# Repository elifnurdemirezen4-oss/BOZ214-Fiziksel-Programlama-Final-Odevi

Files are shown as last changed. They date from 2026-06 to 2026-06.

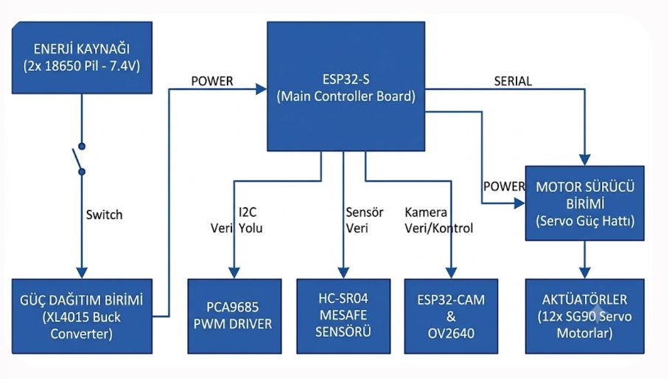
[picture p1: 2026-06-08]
docs/şema.jpeg

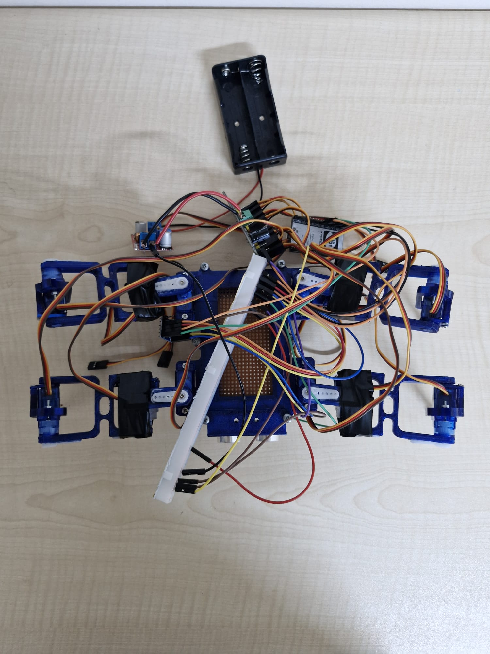
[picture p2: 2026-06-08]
docs/dort_bacak1.jpeg

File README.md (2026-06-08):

dort_bacak2

# SPİDER ASSİST (DÖRT BACAK)

Bu proje, her bacağında iki eklem (Coxa ve Tibia) bulunan, toplam 8 servo motor ile hareket eden dört bacaklı (quadruped) bir robotun donanım ve yazılım altyapısını içermektedir. Sistem, ESP32 mikrodenetleyicisi üzerinden Bluetooth Low Energy (BLE) protokolü ile haberleşmekte ve Python tabanlı bir masaüstü arayüzü ile kontrol edilmektedir.

## 🎯 Proje Amacı 

Bu projenin temel amacı, hareket kısıtlılığı yaşayan bireylerin çevresel bağımsızlıklarını artırmak üzere; Bluetooth Low Energy (BLE) üzerinden uzaktan kontrol edilebilen, otonom engel algılama refleksine sahip, 8 serbestlik dereceli (8-DOF) bir masaüstü mekatronik robot asistan geliştirmektir. Geliştirilen bu sistem, kullanıcı dostu bir arayüz ile mekatronik donanımı entegre ederek, engelli bireylerin asgari fiziksel eforla bulundukları kısıtlı alanlarda güvenli bir şekilde erişim ve kontrol sağlamalarına olanak tanımayı hedeflemektedir.
## 📌 Proje Özellikleri

* **Kablosuz Kontrol:** BLE (Bluetooth Low Energy) teknolojisi kullanılarak düşük gecikmeli, asenkron motor kontrolü.
* **Engelden Kaçma Otonomisi:** HC-SR04 ultrasonik sensörü ile 15 cm altındaki engellerin tespiti. Engel algılandığında motorlar durdurulur ve arayüze anlık uyarı gönderilir.
* **Yumuşak Hareket Algoritması (Smooth Kinematics):** Servo motorların ani akım çekmesini ve mekanik hasar görmesini engellemek amacıyla `yumusakHareket` fonksiyonu ile kademeli açı geçişleri.
* **Güç Tasarrufu:** Robot durur pozisyondayken PWM sinyalleri kesilerek motorlar serbest bırakılır (`motorlariSerbestBirak`), böylece aşırı ısınma ve güç tüketimi önlenir.
* **Kullanıcı Arayüzü (GUI):** Python `Tkinter` ve `Bleak` kütüphaneleri kullanılarak geliştirilmiş, klavye kısayollarını (W, A, S, X) destekleyen asenkron masaüstü kontrol yazılımı.

## 🛠️ Donanım Gereksinimleri

* 1x ESP32 (veya ESP32-S3) Mikrodenetleyici
* 1x PCA9685 16-Kanal PWM Servo Sürücü Modülü (I2C Adresi: 0x40)
* 8x Servo Motor (SG90, MG90S vb.)
* 1x HC-SR04 Ultrasonik Mesafe Sensörü
* 1x XL4015 Voltaj Düşürücü (Buck)
* 1x 3.3V-5V Lojik Dönüştürücü
* 2x 18650 Li-ion Pil (Sistem güç kaynağı)

## 🖨️ 3D Baskı ve Mekanik Tasarım

Robotun fiziksel gövdesini ve eklem parçalarını oluşturmak için gerekli olan tüm `.stl` uzantılı 3D model dosyaları `3d_models/` klasöründe sunulmuştur. Parçaların üretimi için standart PLA malzeme ve optimum dayanıklılık/ağırlık dengesi için %30 doluluk (infill) oranı önerilmektedir.

## 💻 Kullanılan Teknolojiler ve Kütüphaneler

**Gömülü Yazılım (C++ / Arduino IDE):**
* `Wire.h` - I2C iletişimi
* `Adafruit_PWMServoDriver.h` - PCA9685 kontrolü
* `BLEDevice.h`, `BLEServer.h`, `BLEUtils.h`, `BLE2902.h` - Bluetooth BLE protokolü

**Masaüstü Yazılımı (Python):**
* `tkinter` - Grafiksel Kullanıcı Arayüzü (GUI)
* `asyncio` & `threading` - Asenkron BLE haberleşmesi ve arayüz tepkiselliği
* `bleak` - Platform bağımsız BLE istemci bağlantısı

## 🚀 Kurulum ve Çalıştırma

### 1. Mikrodenetleyicinin Programlanması
1. Arduino IDE üzerinde ESP32 kart paketinin yüklü olduğundan emin olun.
2. `Adafruit PWM Servo Driver Library` kütüphanesini kütüphane yöneticisinden kurun.
3. Repoda bulunan `.ino` uzantılı dosyayı ESP32 kartınıza yükleyin. 

### 2. Python Arayüzünün Çalıştırılması
Python ortamınızda gerekli kütüphaneleri kurun:
```bash
pip install bleak asyncio.
```
### 3. `software/python_ble_gui` dizinine gidin ve arayüzü başlatın:
   ```bash
   cd software/python_ble_gui
   python controller.py
   ```
### 4. 
Arayüz açıldığında "Bluetooth ile Robota Bağlan" butonuna tıklayarak eşleşmeyi tamamlayın. Klavye üzerinden (W, A, S) kısayollarını kullanarak veya butonlarla robotu kontrol edebilirsiniz.

## 👥 Proje Yürütücüleri
* Furkan Solmaz
* Elif Nur Demirezen

## 📄 Lisans

Bu proje MIT Lisansı ile lisanslanmıştır. Daha fazla bilgi için `LICENSE` dosyasına göz atabilirsiniz.

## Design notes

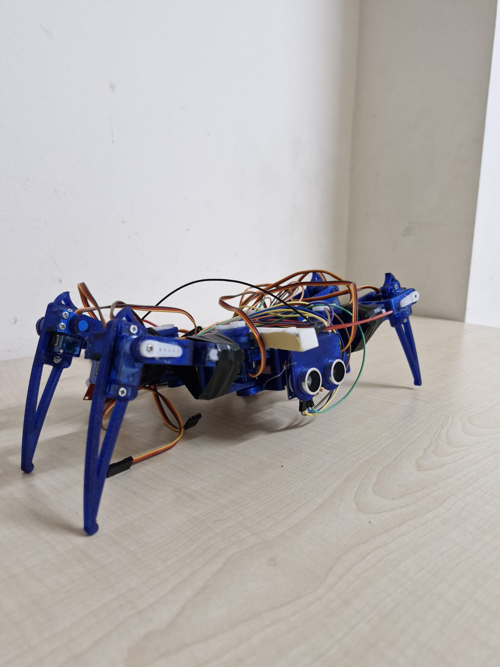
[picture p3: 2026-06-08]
docs/dort_bacak3.jpeg

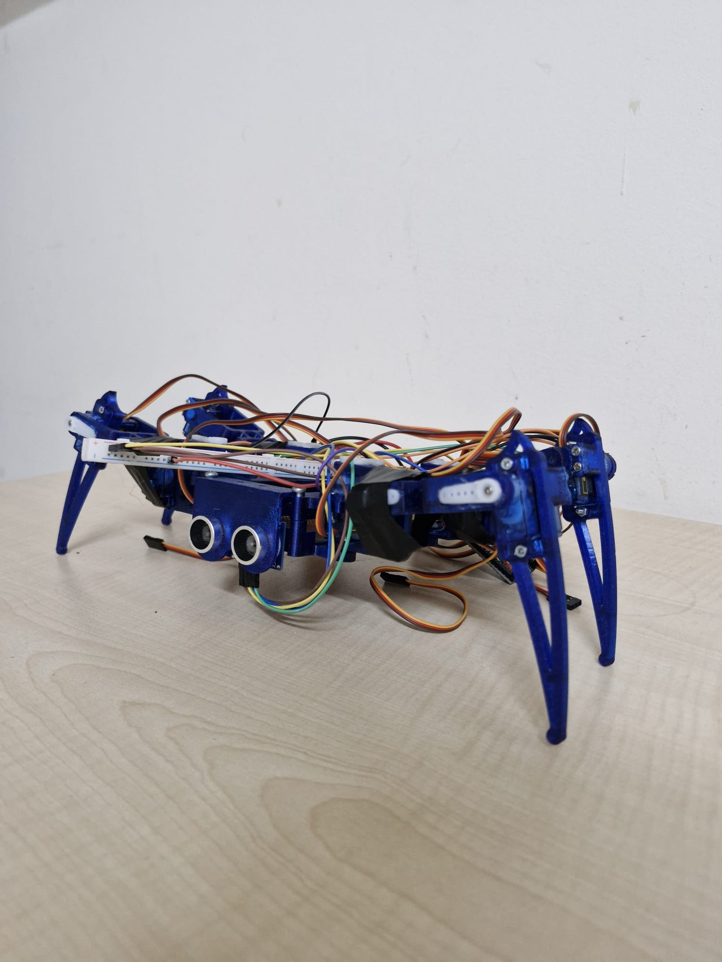
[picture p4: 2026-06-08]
docs/dortbacak4.jpeg

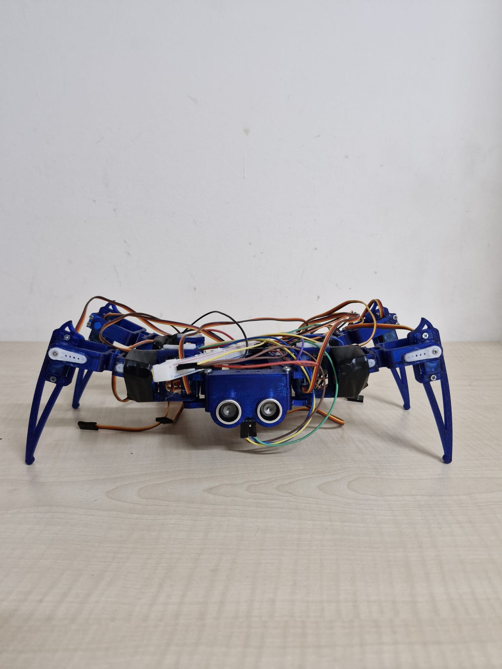
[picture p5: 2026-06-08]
docs/dort_bacak2.jpeg

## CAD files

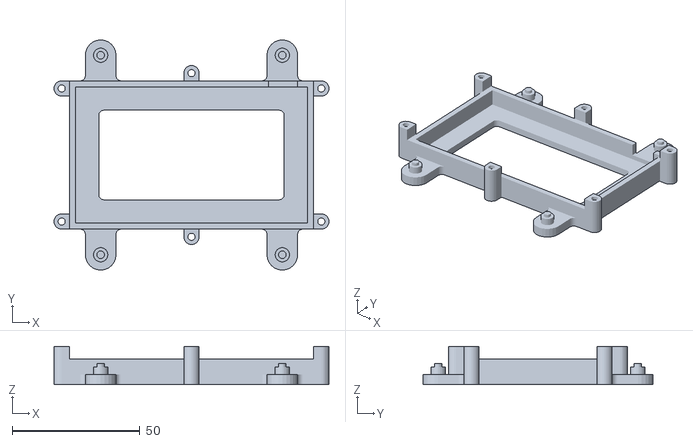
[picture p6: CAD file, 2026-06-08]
3d_models/body_alt_final.stl
107.5 x 90.0 x 15.0

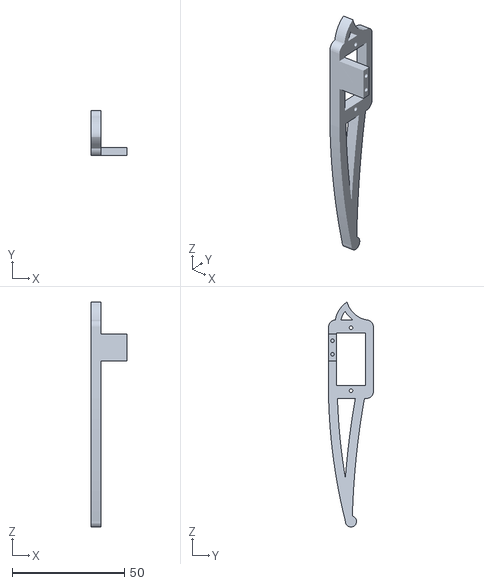
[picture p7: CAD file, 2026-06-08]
3d_models/tibia_right_repair.stl
16.0 x 20.0 x 100.2

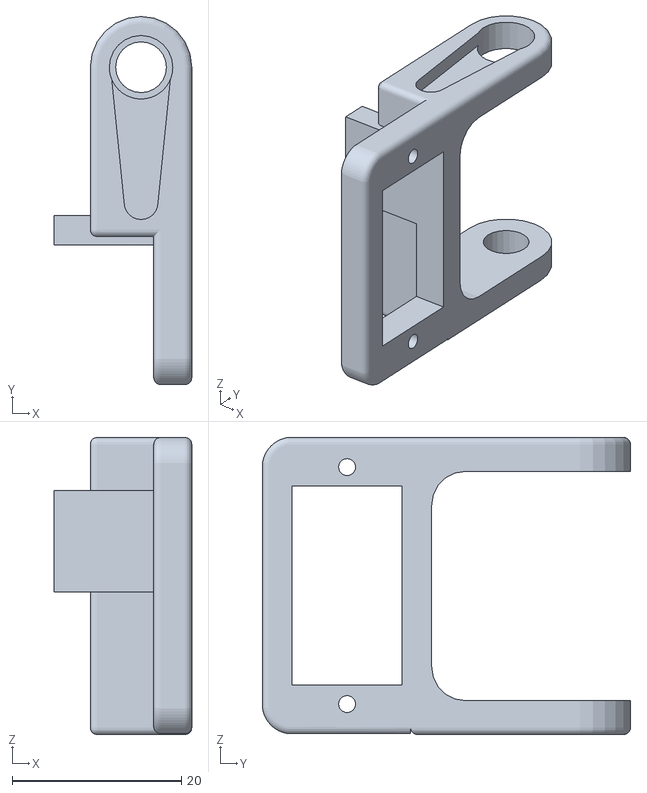
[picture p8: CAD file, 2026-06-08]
3d_models/coxa_left_repair.stl
16.3 x 43.5 x 35.1

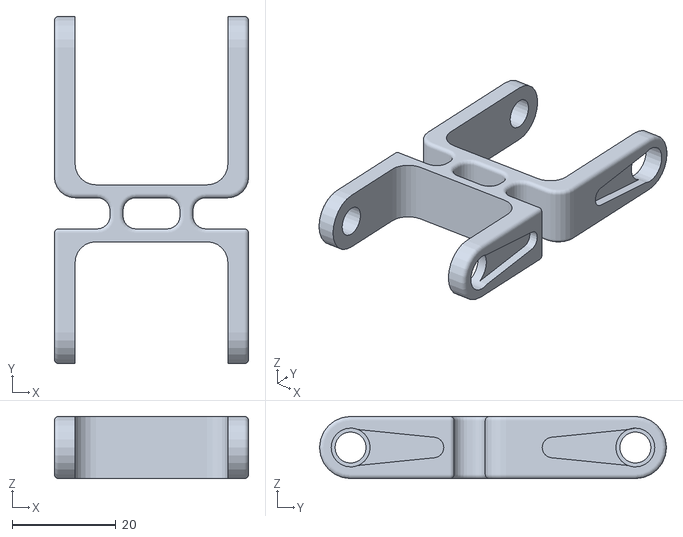
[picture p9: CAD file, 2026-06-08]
3d_models/femur_son_repair.stl
37.5 x 67.0 x 12.0

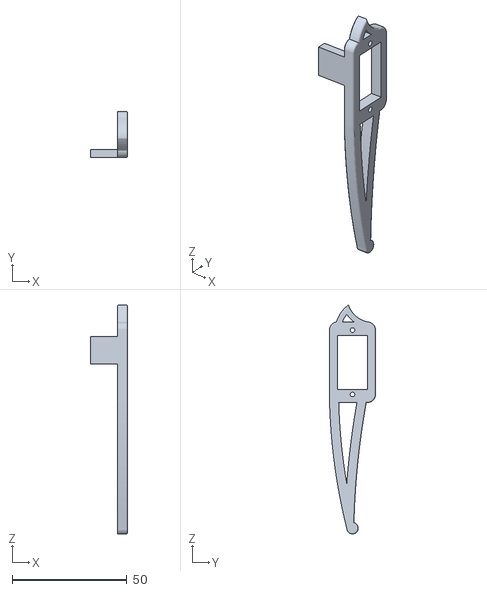
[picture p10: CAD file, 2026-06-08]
3d_models/tibia_left_repair.stl
16.3 x 20.0 x 99.7

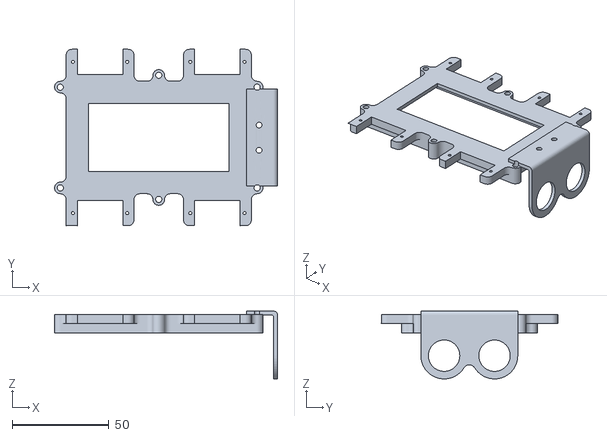
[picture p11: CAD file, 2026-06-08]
3d_models/body_üst_repair.stl
115.0 x 91.0 x 35.0

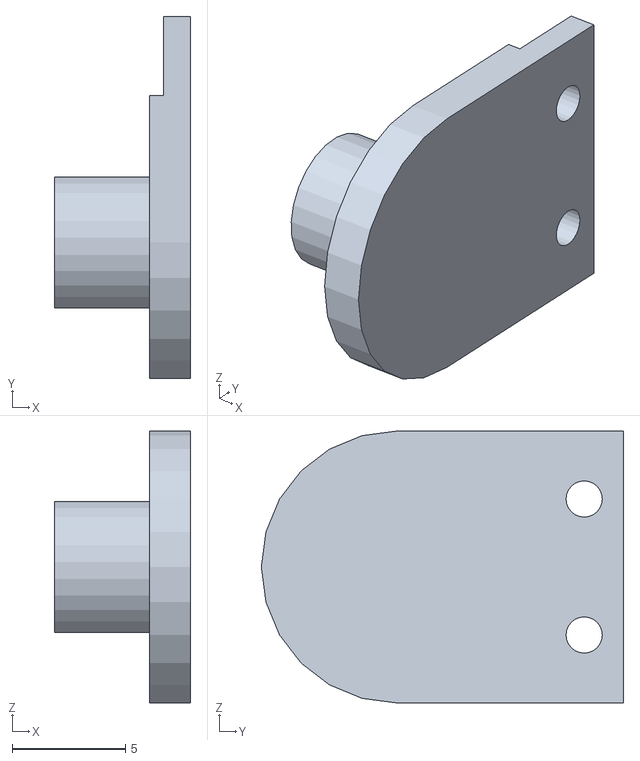
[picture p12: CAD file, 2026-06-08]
3d_models/hold_final.stl
6.00 x 16.0 x 12.0

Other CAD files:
3d_models/coxa_right_repair.stl

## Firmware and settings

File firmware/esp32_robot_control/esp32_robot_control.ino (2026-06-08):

// ================= KÜTÜPHANELER =================
#include <Wire.h>                  // I2C haberleşme protokolü (PCA9685 sürücüsü için gerekli)
#include <Adafruit_PWMServoDriver.h>// 16 kanallı PWM servo sürücü kartının kütüphanesi
#include <BLEDevice.h>             // ESP32 Bluetooth Low Energy (BLE) temel kütüphanesi
#include <BLEServer.h>             // ESP32'yi bir Bluetooth sunucusu yapmak için
#include <BLEUtils.h>              // BLE yardımcı fonksiyonları
#include <BLE2902.h>               // Veri bildirimleri (Notify) için gerekli BLE standardı

// PCA9685 sürücüsünü 0x40 I2C adresiyle başlatıyoruz
Adafruit_PWMServoDriver pwm = Adafruit_PWMServoDriver(0x40);

// ================= BLE (BLUETOOTH) AYARLARI =================
BLEServer *pServer = NULL;
BLECharacteristic * pTxCharacteristic; // ESP32'den veriyi (Tx) göndereceğimiz kanal
bool deviceConnected = false;          // Cihazın bağlı olup olmadığını tutan bayrak (flag)
String bleKomut = "";                  // Gelen komutu geçici olarak saklayacağımız değişken

// BLE cihazlarının birbirini tanıması için gereken evrensel benzersiz kimlikler (UUID)
#define SERVICE_UUID           "6E400001-B5A3-F393-E0A9-E50E24DCCA9E" // Ana servis kimliği
#define CHARACTERISTIC_UUID_RX "6E400002-B5A3-F393-E0A9-E50E24DCCA9E" // Veri alma (Receive) kimliği
#define CHARACTERISTIC_UUID_TX "6E400003-B5A3-F393-E0A9-E50E24DCCA9E" // Veri gönderme (Transmit) kimliği

// Bluetooth sunucu olaylarını (bağlanma/kopma) yakalayan sınıf
class MyServerCallbacks: public BLEServerCallbacks {
    void onConnect(BLEServer* pServer) { 
      deviceConnected = true; 
      Serial.println("Bluetooth Baglandi!");
    }
    void onDisconnect(BLEServer* pServer) {
      deviceConnected = false;
      Serial.println("Bluetooth Koptu! Tekrar yayin yapiliyor...");
      pServer->startAdvertising(); // Bağlantı koparsa cihazın tekrar bulunabilir olmasını sağlar
    }
};

// Bluetooth üzerinden gelen verileri dinleyen sınıf
class MyCallbacks: public BLECharacteristicCallbacks {
    void onWrite(BLECharacteristic *pCharacteristic) {
      // Gelen veriyi okuyup String formatına çevirir
      String rxValue = pCharacteristic->getValue();
      
      if (rxValue.length() > 0) {
        rxValue.trim();     // Başındaki ve sonundaki boşlukları temizler
        bleKomut = rxValue; // Ana döngüde işlenmek üzere değişkene aktarır
      }
    }
};

// Çift yönlü iletişim fonksiyonu: Hem seri porta yazdırır hem de bağlıysa BLE üzerinden arayüze/telefona iletir
void bleMesajGonder(String mesaj) {
  Serial.println(mesaj);
  if (deviceConnected) {
    pTxCharacteristic->setValue(mesaj.c_str());
    pTxCharacteristic->notify(); // İstemciye (örn. Python arayüzü) yeni veri olduğunu bildirir
  }
}

// ================= ULTRASONİK SENSÖR PİNLERİ =================
const int TRIG_PIN = 5;  // Sinyal gönderen pin (Tetik)
const int ECHO_PIN = 18; // Yansıyan sinyali okuyan pin
const int ENGEL_MESAFESI = 15; // Robotun durması gereken kritik mesafe (cm)

// ================= PİN HARİTASI (KINEMATİK YAPI) =================
// Robotun 4 bacağının omuz (COXA) ve diz (TIBIA) motorlarının PCA9685 üzerindeki port numaraları
const int PIN_FR_COXA = 0;   const int PIN_FR_TIBIA = 2;  // Ön Sağ (Front Right)
const int PIN_BL_COXA = 8;   const int PIN_BL_TIBIA = 10; // Arka Sol (Back Left)
const int PIN_FL_COXA = 4;   const int PIN_FL_TIBIA = 6;  // Ön Sol (Front Left)
const int PIN_BR_COXA = 12;  const int PIN_BR_TIBIA = 14; // Arka Sağ (Back Right)

// ================= AÇI DEĞERLERİ =================
// PWM sinyali için pulse uzunlukları (Mekanik kalibrasyon değerleri)
const int TIBIA_YERDE = 375;   // Bacağın yere basma açısı
const int TIBIA_HAVADA = 340;  // Bacağın adım atmak için kalkma açısı

// Omuz motorlarının merkez, ileri adım ve geri adım kalibrasyon açıları
const int FR_COXA_CENTER = 375; const int FR_COXA_ILERI = 395; const int FR_COXA_GERI = 355;
const int BR_COXA_CENTER = 375; const int BR_COXA_ILERI = 395; const int BR_COXA_GERI = 355;
const int FL_COXA_CENTER = 375; const int FL_COXA_ILERI = 355; const int FL_COXA_GERI = 395;
const int BL_COXA_CENTER = 375; const int BL_COXA_ILERI = 355; const int BL_COXA_GERI = 395;

// ================= HAFIZA DEĞİŞKENLERİ =================
int mevcutKonum[16];           // Her bir servonun anlık pozisyonunu tutan dizi (Yumuşak hareket için gerekli)
String aktifDurum = "DUR";     // Durum makinesi (State Machine) değişkeni
bool engelVarMi = false;       // Sensör engel tespit etti mi durumunu tutar

// ================= MESAFE ÖLÇÜM FONKSİYONU =================
long mesafeOlc() {
  // Sensörü temizle ve 10 mikrosaniyelik bir ses dalgası gönder
  digitalWrite(TRIG_PIN, LOW); delayMicroseconds(2);
  digitalWrite(TRIG_PIN, HIGH); delayMicroseconds(10); digitalWrite(TRIG_PIN, LOW);
  
  // Ses dalgasının gidip gelme süresini ölç (Zaman aşımı: 30000 mikrosaniye)
  long duration = pulseIn(ECHO_PIN, HIGH, 30000); 
  if (duration == 0) return 999; // Okuma yapılamadıysa güvenli bir yüksek değer döndür
  
  // Yol = Hız * Zaman formülünden mesafeyi cm cinsinden hesapla (Ses hızı ~0.034 cm/us)
  return duration * 0.034 / 2; 
}
 
// ================= YUMUŞAK HAREKET (İNTERPOLASYON) FONKSİYONU =================
// Motorların ani hareket edip sarsılmasını önler, başlangıç ve hedef açı arasında yavaşça adım atar
void yumusakHareket(int pin, int hedefAci) {
  int baslangic = mevcutKonum[pin];
  int adimGecikmesi = 5; // Hızı belirleyen gecikme süresi
  
  if (baslangic == hedefAci) return; // Zaten hedefteyse işlem yapma
  
  if (baslangic < hedefAci) {
    for (int p = baslangic; p <= hedefAci; p++) { pwm.setPWM(pin, 0, p); delay(adimGecikmesi); }
  } else {
    for (int p = baslangic; p >= hedefAci; p--) { pwm.setPWM(pin, 0, p); delay(adimGecikmesi); }
  }
  mevcutKonum[pin] = hedefAci; // Yeni konumu hafızaya kaydet
  delay(15); 
}

// ================= GÜÇ KORUMA FONKSİYONU =================
// Motorlara giden PWM sinyalini keserek aşırı ısınmayı ve güç tüketimini önler
void motorlariSerbestBirak() {
  int butunMotorlar[] = {0, 2, 4, 6, 8, 10, 12, 14};
  for(int i=0; i<8; i++) { pwm.setPWM(butunMotorlar[i], 0, 4096); } // 4096 değeri PWM sinyalini tamamen kapatır
}
 
void setup() {
  Serial.begin(115200); 
  pinMode(TRIG_PIN, OUTPUT); pinMode(ECHO_PIN, INPUT);

  // --- BLE KURULUMU ---
  BLEDevice::init("DORTBACAK_V1"); // Cihazın dışarıdan görünecek adı
  pServer = BLEDevice::createServer();
  pServer->setCallbacks(new MyServerCallbacks());
  BLEService *pService = pServer->createService(SERVICE_UUID);
  
  pTxCharacteristic = pService->createCharacteristic(CHARACTERISTIC_UUID_TX, BLECharacteristic::PROPERTY_NOTIFY);
  pTxCharacteristic->addDescriptor(new BLE2902());
  
  BLECharacteristic * pRxCharacteristic = pService->createCharacteristic(CHARACTERISTIC_UUID_RX, BLECharacteristic::PROPERTY_WRITE);
  pRxCharacteristic->setCallbacks(new MyCallbacks());
  
  pService->start();
  pServer->getAdvertising()->start(); // Cihazı keşfedilebilir hale getir
  // --------------------

  // --- MOTOR SÜRÜCÜ KURULUMU ---
  pwm.begin();
  pwm.setOscillatorFrequency(27000000); // PCA9685 iç osilatör frekansı (hassasiyet için)
  pwm.setPWMFreq(50); delay(100);       // Analog servolar için standart 50Hz (20ms periyot) frekans ayarı
 
  Serial.println("Robot hazirlik pozisyonuna geciyor...");
  int butunMotorlar[] = {0, 2, 4, 6, 8, 10, 12, 14};
  
  // Tüm motorları güvenli başlangıç açısına (merkeze) çek
  for(int i=0; i<8; i++) {
    int pin = butunMotorlar[i];
    pwm.setPWM(pin, 0, 375); mevcutKonum[pin] = 375; delay(200); 
  }
  
  delay(1000); 
  motorlariSerbestBirak(); // Bekleme modunda enerji tasarrufu için motorları sal
  Serial.println("ESP32-S BLE Hazir! Eslenme bekleniyor...");
}
 
void loop() {
  // 1. HABERLEŞME KONTROLÜ: BLE veya Seri Port üzerinden yeni veri var mı?
  String command = "";
  
  if (bleKomut != "") {
    command = bleKomut;
    bleKomut = ""; // İşledikten sonra komut çakışmasını önlemek için temizle
  } 
  else if (Serial.available() > 0) {
    command = Serial.readStringUntil('\n');
    command.trim(); 
  }

  // Komut alındıysa durum makinesini (aktifDurum) güncelle
  if (command != "") {
    if (command == "ILERI" || command == "GERI") {
      aktifDurum = command; 
      Serial.println("Surekli hareket basliyor: " + aktifDurum);
      engelVarMi = false; 
    }
    else if (command == "DUR") {
      aktifDurum = "DUR"; 
      Serial.println("DUR komutu alindi. Robot durduruluyor...");
      motorlariSerbestBirak(); 
    }
  }

  // 2. HAREKET VE GÜVENLİK DÖNGÜSÜ
  if (aktifDurum == "ILERI") {
      // ==== GÜVENLİK REFLEKSİ (ENGELLDEN KAÇINMA) ====
      long mesafe = mesafeOlc();
      
      if (mesafe <= ENGEL_MESAFESI) {
        if (!engelVarMi) { 
            // Engel ilk defa görüldüyse arayüze bilgi gönder ve motorları durdur
            bleMesajGonder("--> DIKKAT! Engel goruldu");
            motorlariSerbestBirak();
            engelVarMi = true;
        }
        delay(100); 
        return; // Engel varken alt satırlardaki yürüyüş koduna geçmesini engeller (döngüyü başa sarar)
      } 
      else {
        if (engelVarMi) { 
            // Engel ortadan kalktıysa arayüze bilgi ver
            bleMesajGonder("--> Engel kalkti");
            engelVarMi = false;
        }
      }
      // ====================================

      // YÜRÜYÜŞ DÖNGÜSÜ (Çapraz Bacak Yürüyüşü - Trot Gait)
      // 1. Aşama: Sağ Ön ve Sol Arka bacakları havaya kaldır
      yumusakHareket(PIN_FR_TIBIA, TIBIA_HAVADA); yumusakHareket(PIN_BL_TIBIA, TIBIA_HAVADA); 
      // Omuzlardan bu iki bacağı ileri atarken, yerdeki bacakları geriye çekerek gövdeyi iter
      yumusakHareket(PIN_FR_COXA, FR_COXA_ILERI); yumusakHareket(PIN_BL_COXA, BL_COXA_ILERI); 
      yumusakHareket(PIN_FL_COXA, FL_COXA_GERI);  yumusakHareket(PIN_BR_COXA, BR_COXA_GERI);  
      // Kaldırılan bacakları yere bas
      yumusakHareket(PIN_FR_TIBIA, TIBIA_YERDE);  yumusakHareket(PIN_BL_TIBIA, TIBIA_YERDE);  
     
      // 2. Aşama: Sol Ön ve Sağ Arka bacakları havaya kaldır
      yumusakHareket(PIN_FL_TIBIA, TIBIA_HAVADA); yumusakHareket(PIN_BR_TIBIA, TIBIA_HAVADA); 
      // Havada olanları ileri at, yerde olanları geri çek
      yumusakHareket(PIN_FL_COXA, FL_COXA_ILERI); yumusakHareket(PIN_BR_COXA, BR_COXA_ILERI); 
      yumusakHareket(PIN_FR_COXA, FR_COXA_GERI);  yumusakHareket(PIN_BL_COXA, BL_COXA_GERI);  
      // Kaldırılan bacakları yere bas
      yumusakHareket(PIN_FL_TIBIA, TIBIA_YERDE);  yumusakHareket(PIN_BR_TIBIA, TIBIA_YERDE);  
  }
  else if (aktifDurum == "GERI") {
      // Geri yürüyüş döngüsü: İleri yürüyüşün omuz motorlarındaki yönlerinin tersine çevrilmiş hali
      yumusakHareket(PIN_FR_TIBIA, TIBIA_HAVADA); yumusakHareket(PIN_BL_TIBIA, TIBIA_HAVADA); 
      yumusakHareket(PIN_FR_COXA, FR_COXA_GERI);  yumusakHareket(PIN_BL_COXA, BL_COXA_GERI); 
      yumusakHareket(PIN_FL_COXA, FL_COXA_ILERI); yumusakHareket(PIN_BR_COXA, BR_COXA_ILERI);  
      yumusakHareket(PIN_FR_TIBIA, TIBIA_YERDE);  yumusakHareket(PIN_BL_TIBIA, TIBIA_YERDE);  
     
      yumusakHareket(PIN_FL_TIBIA, TIBIA_HAVADA); yumusakHareket(PIN_BR_TIBIA, TIBIA_HAVADA); 
      yumusakHareket(PIN_FL_COXA, FL_COXA_GERI);  yumusakHareket(PIN_BR_COXA, BR_COXA_GERI); 
      yumusakHareket(PIN_FR_COXA, FR_COXA_ILERI); yumusakHareket(PIN_BL_COXA, BL_COXA_ILERI);  
      yumusakHareket(PIN_FL_TIBIA, TIBIA_YERDE);  yumusakHareket(PIN_BR_TIBIA, TIBIA_YERDE);  
  }
}
